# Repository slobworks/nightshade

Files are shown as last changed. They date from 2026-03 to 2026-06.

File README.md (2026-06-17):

bleh
bleh_back

This is, for all intents and purposes, a maxed-out version of the open-source, Nightshade CL-GD542x VGA card project. Basically, what this board offers the regular version is support for up to 2 megabytes of FPM DRAM installed. This board has been built by me and its basic operation verified (it works). I have _not_ tested the VESA Feature Connector, however; I am not certain that the pinout is compliant.

It's got the usual Nightshade features:

- Dedicated regulator for the internal RAMDAC, and TL431+MMBT3904 IREF circuit, for improved video quality
- Four-layer PCB and hand-tuned return paths for (hopefully) reduced noise pickup
- Supports N-well CL-GD542x chips, starting from late revision CL-GD5422 all the way up to CL-GD5429 (though you may have to change strapping resistors as needed)
- Custom footprints with longer pads for the more difficult components, to ease hand assembly using a soldering iron
- Emphasis on implementation simplicity (added regulator aside) for reduced part count and effort needed to assemble the board
- Silkscreen decorations drawn by me

The Pro variant was originally intended as a mild satire of what the 'ideal' Cirrus ISA VGA card should be, but then it spiralled out of control and became an actually viable product of its own. And it's scalable: if you don't want specific functionality (such as the second megabyte, serial EEPROM, VESA Feature Connector or the high byte BIOS socket plus its accompanying 74HCT244), then simply don't fit them.

BIOS files (apart from SEEPROM image) *not* provided here, due to uncertainty regarding the copyright. It does require a _non-interleaved_ VGA BIOS in order for it to work; most of the Cirrus BIOS files you find online are 'interleaved'. Depending on the functionality you want:
- If you want to use a BitBLT chip (GD5426 or better) and want to experiment with 2MB, you can nonetheless find a suitable (albeit padded to 64K) file, isamalaysia.bin (1.41), on the CL-GD5428 page of the VGA Legacy MkIII museum. This file has been tested and works; if your EPROM programmer complains about file size when writing 27C256, then split the file into two 32768-byte files, and use the first half to program your BIOS chips. (If you're using a 27C512, _don't_ burn this file directly to it even though it's padded; you must first split the file, and then double up the first, non-empty half. See the following paragraph.)
- If you want Serial EEPROM functionality but aren't planning on using 2MB, then you'll need a BIOS from an ISA GD542x card in order for the Serial EEPROM function to work properly. (One such BIOS that was tested to work was from a Gainward GD5424 ISA VGA card.) You will also need to pre-initialize the serial EEPROM with a valid image *before* soldering the 93C46A to the card.
- On the other hand, if all you want is just a working GD542x card, and don't care about either Serial EEPROM or 2MB, then just use whatever non-scrambled GD542x BIOS is convenient. (The beforementioned isamalaysia.bin is a reasonable candidate.)

For 27C512s, you must double up the _non-blank_ contents of the BIOS (in DOS or Windows command line, a command like 'copy /b vgabios.bin+vgabios.bin outbios.bin' is sufficient).

16-bit BIOS mode requires two PROM/EPROM/EEPROM/flash chips with identical BIOS contents.

Made in KiCAD 9.x.
Also includes gerber files so you can try it out for yourself.

Bill of materials (all parts are Surface Mount Device / SMD unless indicated otherwise):
- 1x Cirrus Logic CL-GD542x graphic chip, PQFP-160
- 2x (1MB) or 4x (2MB) 424260-compatible FPM 256Kx16 DRAM chips rated at least 70ns, SOJ-40 (this might require you to cannibalize parts from other broken cards, or roll the dice on eBay)
- 1x DIP-28 through-hole socket (2 needed for 16-bit BIOS mode)
- 1x 27C256 or compatible PROM/EPROM/flash ROM chip for BIOS, DIP-28 (2 needed for 16-bit BIOS mode)
- 1x 14.31818MHz 5032 SMD crystal (https://www.digikey.com/en/products/detail/qst/QT532G-14-31818MBBK-T/26975047)
- 1x 74HCT244, SSOP-20 or TSSOP-20 (2 needed for 16-bit BIOS mode)
- 1x LF50 or 78M05 5V LDO regulator, DPAK (https://www.digikey.com/en/products/detail/stmicroelectronics/LF50CDT-TR/591636)
- 1x TL431DBZ, SOT-23-3 (https://www.digikey.com/en/products/detail/texas-instruments/TL431BQDBZR/714694)
- 1x MMBT3904 NPN small signal transistor, SOT-23-3  (https://www.digikey.com/en/products/detail/taiwan-semiconductor-corporation/MMBT3904H-RFG/26741367)
- (Optional) 1x NM93C46 or equivalent SOIC-8 serial EEPROM (you need the one with x16 mode support) - you WILL need to initialize the serial EEPROM with a valid image *before* assembling it onto the card. Please check the directory /seeprom to get a generic image with all sub-1280x1024 SVGA refresh rates set to 60 Hz. You will also need a BIOS image from an *ISA* GD542x card for the SEEPROM functionality to work; most generic 542x BIOSes were compiled for the VLB variants, which this functionality is disabled.
- 3x 2-pin, 2.54mm pitch male jumper connectors
- (Optional) 1x 2x13 pin, 2.52mm pitch male header for VESA Feature Connector
- 1x DSUB-15-HD right angle through hole VGA connector (something akin to this: https://www.digikey.com/en/products/detail/assmann-wsw-components/A-HDF15A-KG-TAXB/1241905)
- 25x 0.1uF 0805/2012 metric ceramic caps of X5R/X7R type (https://www.digikey.com/en/products/detail/samsung-electro-mechanics/CL21B104KACNNNC/3886757)
- 7x 10uF 16V+ 2012/3216 metric ceramic caps of X5R/X7R type (these work well: https://www.digikey.com/en/products/detail/samsung-electro-mechanics/CL31B106KAHNNNE/3887462)
- 1x 22~100uF 16V 5mm x 5.3mm (or equivalent) SMD electrolytic capacitor - the higher the uF value, the better the performance, up to a point
- 4x 2.2u 0805/2012 metric ceramic caps of X5R/X7R type (1uF will likely work too)
- 1x 0.01uF / 10nF 0805/2012 metric ceramic capacitor of X5R/X7R type
- 5x 47pF 0805/2012 metric ceramic caps of C0G type
- 2x 18pF 0805/2012 metric ceramic caps of C0G type
- 1x 10K ohm 0805/2012 metric resistor
- 6x 6.8K ohm 0805/2012 metric resistors
- 5x 1K ohm 0805/2012 metric resistor
- 1x 300 ohm 0805/2012 metric resistor
- 1x 100 ohm 0805/2012 metric resistor
- 5x 75 ohm 0805/2012 metric resistors
- 1x 47 ohm 0805/2012 metric resistor
- 6x 33 ohm 0805/2012 metric resistors
- 3x 16 ohm 0805/2012 metric resistors
- (Optional) 1x PTC resettable, 9V 200mA, 0805/2012 metric polyfuse (https://www.digikey.com/en/products/detail/littelfuse-inc/0805L020YR/1212820) - this is only needed if you want to supply +5V to pin 9 of the VGA connector
- 3x 0.22~22 ohm @ 100MHz, 1210/3216 metric ferrite beads

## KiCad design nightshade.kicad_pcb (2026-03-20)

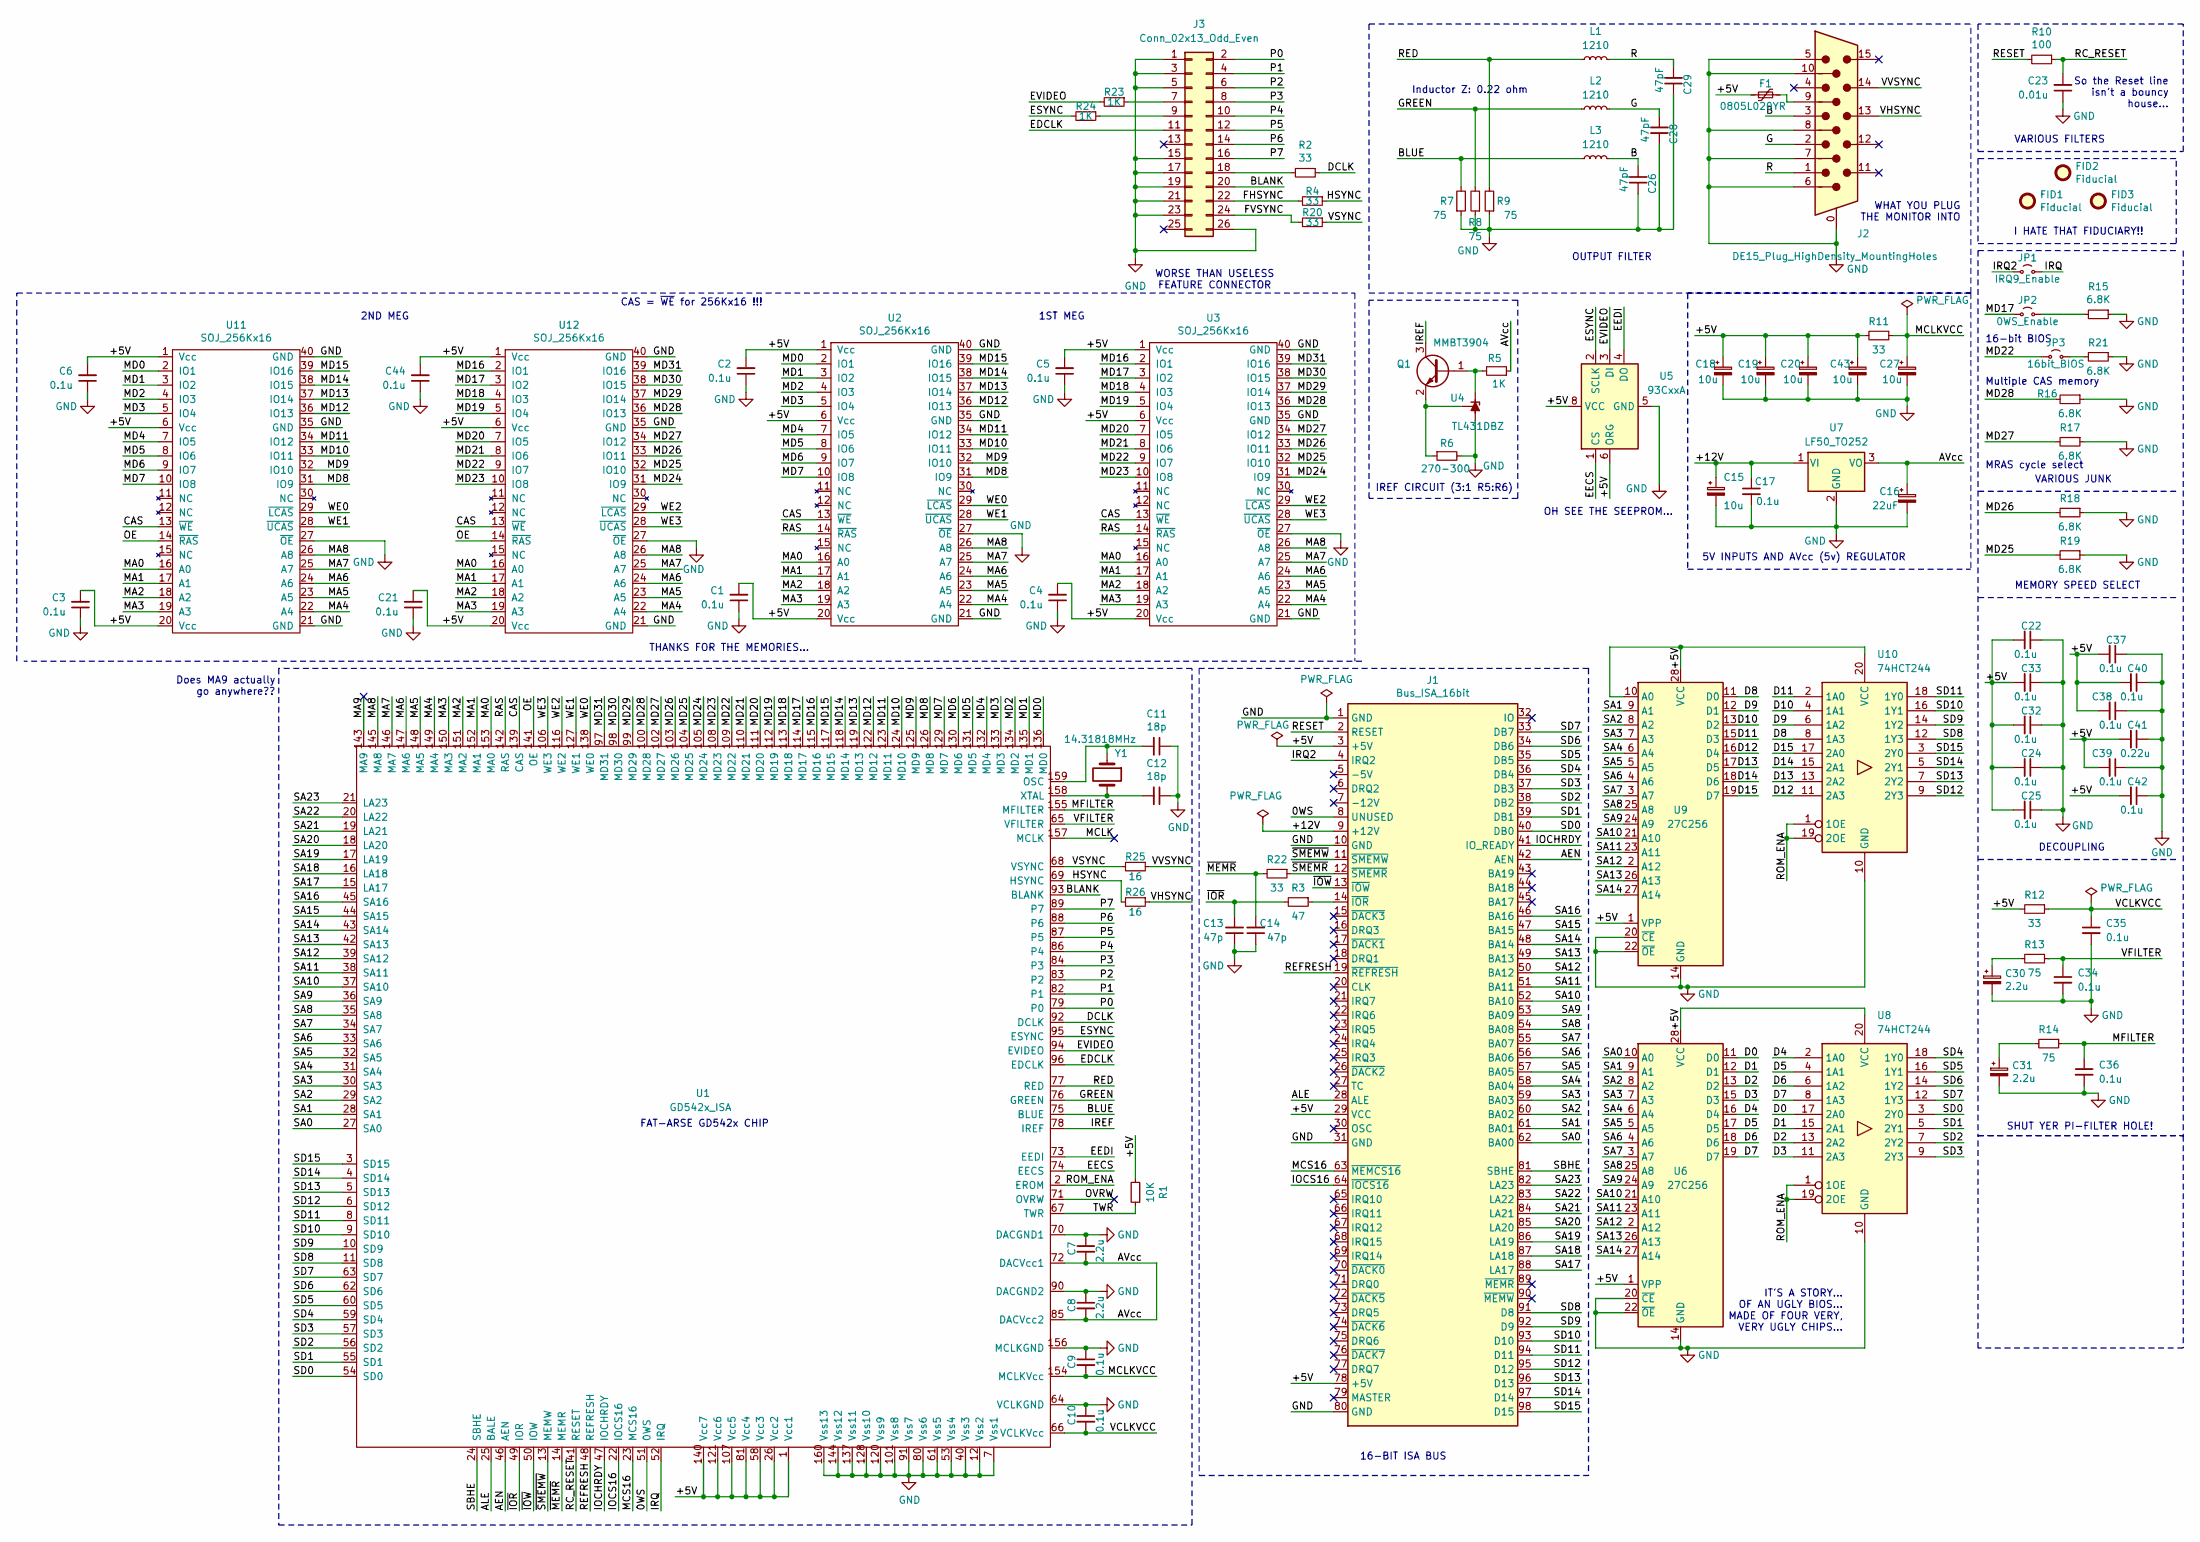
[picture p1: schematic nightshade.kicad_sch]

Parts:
C1, C2, C3, C4, C5, C6, C9, C10, C17, C21, C22, C24, C25, C32, C33, C34, C35, C36, C37, C38, C39, C40, C42, C44: 0.1u; C_0805_2012Metric
C7, C8: 2.2u; C_1206_3216Metric
C11, C12: 18p; C_0805_2012Metric
C13, C14: 47p; C_0805_2012Metric
C15, C18, C19, C20, C27, C43: 10u; C_1206_3216Metric
C16: 22uF; CP_Elec_5x5.3
C23: 0.01u; C_0805_2012Metric
C26, C28, C29: 47pF; C_0603_1608Metric
C30, C31: 2.2u; C_0805_2012Metric
C41: 0.22u; C_0805_2012Metric
F1: 0805L020YR; Fuse_0805_2012Metric
FID1, FID2, FID3: Fiducial; Fiducial_1mm_Mask2mm
J1: Bus_ISA_16bit; BUS_AT
J2: DE15_Plug_HighDensity_MountingHoles; DSUB-15-HD
J3: Conn_02x13_Odd_Even; PinHeader_2x13_P2.54mm_Vertical
JP1: IRQ9_Enable; PinHeader_1x02_P2.54mm_Vertical
JP2: 0WS_Enable; PinHeader_1x02_P2.54mm_Vertical
JP3: 16bit_BIOS; PinHeader_1x02_P2.54mm_Vertical
L1, L2, L3: 1210; L_1210_3225Metric
Q1: MMBT3904; SOT-23
R1: 10K; R_0805_2012Metric
R2, R4, R11, R12, R20: 33; R_0603_1608Metric
R3: 47; R_0805_2012Metric
R5: 1K; R_0805_2012Metric
R6: 270-300; R_0805_2012Metric
R7, R8, R9, R13, R14: 75; R_0805_2012Metric
R10: 100; R_0805_2012Metric
R15, R16, R17, R18, R19, R21: 6.8K; R_0805_2012Metric
R22: 33; R_0805_2012Metric
R23, R24: 1K; R_0603_1608Metric
R25, R26: 16; R_0805_2012Metric
U1: GD542x_ISA; PQFP-160_28x28mm_P0.65mm
U2, U3, U11, U12: SOJ_256Kx16; SOJ-40_10.16x26.44mm_P1.27mm
U4: TL431DBZ; SOT-23
U5: 93CxxA; SOIC-8_DMP-8
U6, U9: 27C256; DIP-28_W15.24mm_Socket
U7: LF50_TO252; TO-252-2
U8, U10: 74HCT244; SSOP-20_4.4_5.3x6.5mm_P0.65mm
Y1: 14.31818MHz; Crystal_SMD_5032-2Pin_5.0x3.2mm_HandSoldering

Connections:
/0WS: J1.8 (UNUSED), U1.51 (0WS)
/+5V: C1.2, C2.2, C3.2, C4.2, C5.2, C6.2, C18.1, C19.1, C20.1, C21.2, C22.2, C24.2, C25.2, C32.2, C33.2, C37.2, C38.2, C39.2, C40.2, C41.2, C42.2, C43.1, C44.2, F1.1, J1.3 (+5V), J1.29 (VCC), J1.78 (+5V), R1.2, R11.2, R12.2, U1.1 (Vcc1), U1.26 (Vcc2), U1.58 (Vcc3), U1.81 (Vcc4), U1.107 (Vcc5), U1.121 (Vcc6), U1.140 (Vcc7), U2.1 (Vcc), U2.6 (Vcc), U2.20 (Vcc), U3.1 (Vcc), U3.6 (Vcc), U3.20 (Vcc), U5.6 (ORG), U5.8 (VCC), U6.1 (VPP), U6.28 (VCC), U8.20 (VCC), U9.1 (VPP), U9.10 (A0), U9.28 (VCC), U10.20 (VCC), U11.1 (Vcc), U11.6 (Vcc), U11.20 (Vcc), U12.1 (Vcc), U12.6 (Vcc), U12.20 (Vcc)
/+12V: C15.1, C17.1, J1.9 (+12V), U7.1 (VI)
/AEN: J1.42 (AEN), U1.46 (AEN)
/ALE: J1.28 (ALE), U1.25 (BALE)
/AVcc: C7.2, C8.2, C16.1, R5.1, U1.72 (DACVcc1), U1.85 (DACVcc2), U7.3 (VO)
/B: C26.2, J2.3, L3.2
/BLANK: J3.20, U1.93 (BLANK)
/BLUE: L3.1, R7.2, U1.75 (BLUE)
/CAS: U1.139 (CAS), U2.13 (~WE), U3.13 (~WE), U11.13 (~WE), U12.13 (~WE)
/D0: U6.11 (D0), U8.17 (2A0)
/D1: U6.12 (D1), U8.15 (2A1)
/D2: U6.13 (D2), U8.13 (2A2)
/D3: U6.15 (D3), U8.11 (2A3)
/D4: U6.16 (D4), U8.2 (1A0)
/D5: U6.17 (D5), U8.4 (1A1)
/D6: U6.18 (D6), U8.6 (1A2)
/D7: U6.19 (D7), U8.8 (1A3)
/D8: U9.11 (D0), U10.8 (1A3)
/D9: U9.12 (D1), U10.6 (1A2)
/D10: U9.13 (D2), U10.4 (1A1)
/D11: U9.15 (D3), U10.2 (1A0)
/D12: U9.16 (D4), U10.11 (2A3)
/D13: U9.17 (D5), U10.13 (2A2)
/D14: U9.18 (D6), U10.15 (2A1)
/D15: U9.19 (D7), U10.17 (2A0)
/DCLK: R2.1, U1.92 (DCLK)
/EDCLK: J3.11, U1.96 (EDCLK)
/EECS: U1.74 (EECS), U5.1 (CS)
/EEDI: U1.73 (EEDI), U5.4 (DO)
/ESYNC: R24.2, U1.95 (ESYNC), U5.2 (SCLK)
/EVIDEO: R23.2, U1.94 (EVIDEO), U5.3 (DI)
/FHSYNC: J3.22, R4.2
/FVSYNC: J3.24, R20.2
/G: C28.2, J2.2, L2.2
/GREEN: L2.1, R8.2, U1.76 (GREEN)
/HSYNC: R4.1, R26.2, U1.69 (HSYNC)
/IOCHRDY: J1.41 (IO_READY), U1.47 (IOCHRDY)
/IOCS16: J1.64 (~IOCS16), U1.22 (IOCS16)
/IREF: Q1.3 (C), U1.78 (IREF)
/IRQ: JP1.2 (B), U1.52 (IRQ)
/IRQ2: J1.4 (IRQ2), JP1.1 (A)
/MA0: U1.153 (MA0), U2.16 (A0), U3.16 (A0), U11.16 (A0), U12.16 (A0)
/MA1: U1.152 (MA1), U2.17 (A1), U3.17 (A1), U11.17 (A1), U12.17 (A1)
/MA2: U1.151 (MA2), U2.18 (A2), U3.18 (A2), U11.18 (A2), U12.18 (A2)
/MA3: U1.150 (MA3), U2.19 (A3), U3.19 (A3), U11.19 (A3), U12.19 (A3)
/MA4: U1.149 (MA4), U2.22 (A4), U3.22 (A4), U11.22 (A4), U12.22 (A4)
/MA5: U1.148 (MA5), U2.23 (A5), U3.23 (A5), U11.23 (A5), U12.23 (A5)
/MA6: U1.147 (MA6), U2.24 (A6), U3.24 (A6), U11.24 (A6), U12.24 (A6)
/MA7: U1.146 (MA7), U2.25 (A7), U3.25 (A7), U11.25 (A7), U12.25 (A7)
/MA8: U1.145 (MA8), U2.26 (A8), U3.26 (A8), U11.26 (A8), U12.26 (A8)
/MA9: U1.143 (MA9)
/MCLK: U1.157 (MCLK)
/MCLKVCC: C9.2, C27.1, R11.1, U1.154 (MCLKVcc)
/MCS16: J1.63 (~MEMCS16), U1.23 (MCS16)
/MD0: U1.136 (MD0), U2.2 (IO1), U11.2 (IO1)
/MD1: U1.135 (MD1), U2.3 (IO2), U11.3 (IO2)
/MD2: U1.134 (MD2), U2.4 (IO3), U11.4 (IO3)
/MD3: U1.133 (MD3), U2.5 (IO4), U11.5 (IO4)
/MD4: U1.132 (MD4), U2.7 (IO5), U11.7 (IO5)
/MD5: U1.131 (MD5), U2.8 (IO6), U11.8 (IO6)
/MD6: U1.130 (MD6), U2.9 (IO7), U11.9 (IO7)
/MD7: U1.129 (MD7), U2.10 (IO8), U11.10 (IO8)
/MD8: U1.126 (MD8), U2.31 (IO9), U11.31 (IO9)
/MD9: U1.125 (MD9), U2.32 (IO10), U11.32 (IO10)
/MD10: U1.124 (MD10), U2.33 (IO11), U11.33 (IO11)
/MD11: U1.123 (MD11), U2.34 (IO12), U11.34 (IO12)
/MD12: U1.122 (MD12), U2.36 (IO13), U11.36 (IO13)
/MD13: U1.119 (MD13), U2.37 (IO14), U11.37 (IO14)
/MD14: U1.118 (MD14), U2.38 (IO15), U11.38 (IO15)
/MD15: U1.117 (MD15), U2.39 (IO16), U11.39 (IO16)
/MD16: U1.115 (MD16), U3.2 (IO1), U12.2 (IO1)
/MD17: JP2.1 (A), U1.114 (MD17), U3.3 (IO2), U12.3 (IO2)
/MD18: U1.113 (MD18), U3.4 (IO3), U12.4 (IO3)
/MD19: U1.112 (MD19), U3.5 (IO4), U12.5 (IO4)
/MD20: U1.111 (MD20), U3.7 (IO5), U12.7 (IO5)
/MD21: U1.110 (MD21), U3.8 (IO6), U12.8 (IO6)
/MD22: JP3.1 (A), U1.109 (MD22), U3.9 (IO7), U12.9 (IO7)
/MD23: U1.108 (MD23), U3.10 (IO8), U12.10 (IO8)
/MD24: U1.105 (MD24), U3.31 (IO9), U12.31 (IO9)
/MD25: R19.2, U1.104 (MD25), U3.32 (IO10), U12.32 (IO10)
/MD26: R18.2, U1.103 (MD26), U3.33 (IO11), U12.33 (IO11)
/MD27: R17.2, U1.102 (MD27), U3.34 (IO12), U12.34 (IO12)
/MD28: R16.2, U1.100 (MD28), U3.36 (IO13), U12.36 (IO13)
/MD29: U1.99 (MD29), U3.37 (IO14), U12.37 (IO14)
/MD30: U1.98 (MD30), U3.38 (IO15), U12.38 (IO15)
/MD31: U1.97 (MD31), U3.39 (IO16), U12.39 (IO16)
/MFILTER: C36.1, R14.1, U1.155 (MFILTER)
/OE: U1.141 (OE), U11.14 (~RAS), U12.14 (~RAS)
/OVRW: U1.71 (OVRW)
/P0: J3.2, U1.79 (P0)
/P1: J3.4, U1.82 (P1)
/P2: J3.6, U1.83 (P2)
/P3: J3.8, U1.84 (P3)
/P4: J3.10, U1.86 (P4)
/P5: J3.12, U1.87 (P5)
/P6: J3.14, U1.88 (P6)
/P7: J3.16, U1.89 (P7)
/R: C29.2, J2.1, L1.2
/RAS: U1.142 (RAS), U2.14 (~RAS), U3.14 (~RAS)
/RC_RESET: C23.2, R10.1, U1.41 (RESET)
/RED: L1.1, R9.2, U1.77 (RED)
/REFRESH: J1.19 (~REFRESH), U1.48 (REFRESH)
/RESET: J1.2 (RESET), R10.2
/ROM_ENA: U1.2 (EROM), U8.1 (1OE), U8.19 (2OE), U10.1 (1OE), U10.19 (2OE)
/SA0: J1.62 (BA00), U1.27 (SA0), U6.10 (A0)
/SA1: J1.61 (BA01), U1.28 (SA1), U6.9 (A1), U9.9 (A1)
/SA2: J1.60 (BA02), U1.29 (SA2), U6.8 (A2), U9.8 (A2)
/SA3: J1.59 (BA03), U1.30 (SA3), U6.7 (A3), U9.7 (A3)
/SA4: J1.58 (BA04), U1.31 (SA4), U6.6 (A4), U9.6 (A4)
/SA5: J1.57 (BA05), U1.32 (SA5), U6.5 (A5), U9.5 (A5)
/SA6: J1.56 (BA06), U1.33 (SA6), U6.4 (A6), U9.4 (A6)
/SA7: J1.55 (BA07), U1.34 (SA7), U6.3 (A7), U9.3 (A7)
/SA8: J1.54 (BA08), U1.35 (SA8), U6.25 (A8), U9.25 (A8)
/SA9: J1.53 (BA09), U1.36 (SA9), U6.24 (A9), U9.24 (A9)
/SA10: J1.52 (BA10), U1.37 (SA10), U6.21 (A10), U9.21 (A10)
/SA11: J1.51 (BA11), U1.38 (SA11), U6.23 (A11), U9.23 (A11)
/SA12: J1.50 (BA12), U1.39 (SA12), U6.2 (A12), U9.2 (A12)
/SA13: J1.49 (BA13), U1.42 (SA13), U6.26 (A13), U9.26 (A13)
/SA14: J1.48 (BA14), U1.43 (SA14), U6.27 (A14), U9.27 (A14)
/SA15: J1.47 (BA15), U1.44 (SA15)
/SA16: J1.46 (BA16), U1.45 (SA16)
/SA17: J1.88 (LA17), U1.15 (LA17)
/SA18: J1.87 (LA18), U1.16 (LA18)
/SA19: J1.86 (LA19), U1.17 (LA19)
/SA20: J1.85 (LA20), U1.18 (LA20)
/SA21: J1.84 (LA21), U1.19 (LA21)
/SA22: J1.83 (LA22), U1.20 (LA22)
/SA23: J1.82 (LA23), U1.21 (LA23)
/SBHE: J1.81 (SBHE), U1.24 (SBHE)
/SD0: J1.40 (DB0), U1.54 (SD0), U8.3 (2Y0)
/SD1: J1.39 (DB1), U1.55 (SD1), U8.5 (2Y1)
/SD2: J1.38 (DB2), U1.56 (SD2), U8.7 (2Y2)
/SD3: J1.37 (DB3), U1.57 (SD3), U8.9 (2Y3)
/SD4: J1.36 (DB4), U1.59 (SD4), U8.18 (1Y0)
/SD5: J1.35 (DB5), U1.60 (SD5), U8.16 (1Y1)
/SD6: J1.34 (DB6), U1.62 (SD6), U8.14 (1Y2)
/SD7: J1.33 (DB7), U1.63 (SD7), U8.12 (1Y3)
/SD8: J1.91 (D8), U1.11 (SD8), U10.12 (1Y3)
/SD9: J1.92 (D9), U1.10 (SD9), U10.14 (1Y2)
/SD10: J1.93 (D10), U1.9 (SD10), U10.16 (1Y1)
/SD11: J1.94 (D11), U1.8 (SD11), U10.18 (1Y0)
/SD12: J1.95 (D12), U1.6 (SD12), U10.9 (2Y3)
/SD13: J1.96 (D13), U1.5 (SD13), U10.7 (2Y2)
/SD14: J1.97 (D14), U1.4 (SD14), U10.5 (2Y1)
/SD15: J1.98 (D15), U1.3 (SD15), U10.3 (2Y0)
/TWR: R1.1, U1.67 (TWR)
/VCLKVCC: C10.2, C35.1, R12.1, U1.66 (VCLKVcc)
/VFILTER: C34.1, R13.1, U1.65 (VFILTER)
/VHSYNC: J2.13, R26.1
/VSYNC: R20.1, R25.2, U1.68 (VSYNC)
/VVSYNC: J2.14, R25.1
/WE0: U1.138 (WE0), U2.29 (~LCAS), U11.29 (~LCAS)
/WE1: U1.127 (WE1), U2.28 (~UCAS), U11.28 (~UCAS)
/WE2: U1.116 (WE2), U3.29 (~LCAS), U12.29 (~LCAS)
/WE3: U1.106 (WE3), U3.28 (~UCAS), U12.28 (~UCAS)
/~IOR: C13.2, R3.2, U1.49 (IOR)
/~IOW: J1.13 (~IOW), U1.50 (IOW)
/~MEMR: C14.2, R22.2, U1.14 (MEMR)
/~SMEMR: J1.12 (~SMEMR), R22.1
/~SMEMW: J1.11 (~SMEMW), U1.13 (MEMW)
GND: C1.1, C2.1, C3.1, C4.1, C5.1, C6.1, C7.1, C8.1, C9.1, C10.1, C11.1, C12.1, C13.1, C14.1, C15.2, C16.2, C17.2, C18.2, C19.2, C20.2, C21.1, C22.1, C23.1, C24.1, C25.1, C26.1, C27.2, C28.1, C29.1, C30.2, C31.2, C32.1, C33.1, C34.2, C35.2, C36.2, C37.1, C38.1, C39.1, C40.1, C41.1, C42.1, C43.2, C44.1, J1.1 (GND), J1.10 (GND), J1.31 (GND), J1.80 (GND), J2.0, J2.5, J2.6, J2.7, J2.8, J2.10, J3.1, J3.3, J3.5, J3.15, J3.17, J3.19, J3.21, J3.23, J3.26, R6.2, R7.1, R8.1, R9.1, R15.1, R16.1, R17.1, R18.1, R19.1, R21.1, U1.7 (Vss1), U1.12 (Vss2), U1.40 (Vss3), U1.53 (Vss4), U1.61 (Vss5), U1.64 (VCLKGND), U1.70 (DACGND1), U1.80 (Vss6), U1.90 (DACGND2), U1.91 (Vss7), U1.101 (Vss8), U1.120 (Vss9), U1.128 (Vss10), U1.137 (Vss11), U1.144 (Vss12), U1.156 (MCLKGND), U1.160 (Vss13), U2.21 (GND), U2.27 (~OE), U2.35 (GND), U2.40 (GND), U3.21 (GND), U3.27 (~OE), U3.35 (GND), U3.40 (GND), U4.3 (A), U5.5 (GND), U6.14 (GND), U6.20 (~CE), U6.22 (~OE), U7.2 (GND), U8.10 (GND), U9.14 (GND), U9.20 (~CE), U9.22 (~OE), U10.10 (GND), U11.21 (GND), U11.27 (~OE), U11.35 (GND), U11.40 (GND), U12.21 (GND), U12.27 (~OE), U12.35 (GND), U12.40 (GND)
unnamed: C30.1, R13.2
unnamed: C31.1, R14.2
unnamed: F1.2, J2.9
unnamed: J1.14 (~IOR), R3.1
unnamed: J3.7, R23.1
unnamed: J3.9, R24.1
unnamed: J3.18, R2.2
unnamed: JP2.2 (B), R15.2
unnamed: JP3.2 (B), R21.2
unnamed: Q1.1 (B), R5.2, U4.1 (K)
unnamed: Q1.2 (E), R6.1, U4.2 (REF)
unnamed: C11.2, U1.159 (OSC), Y1.1
unnamed: C12.2, U1.158 (XTAL), Y1.2

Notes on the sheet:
FAT-ARSE GD542x CHIP
16-BIT ISA BUS
WHAT YOU PLUG THE MONITOR INTO
DECOUPLING
So the Reset line isn't a bouncy house...
MRAS cycle select
THANKS FOR THE MEMORIES...
1ST MEG
Does MA9 actually go anywhere??
IREF CIRCUIT (3:1 R5:R6)
Inductor Z: 0.22 ohm
SHUT YER PI-FILTER HOLE!
16-bit BIOS
OH SEE THE SEEPROM...
VARIOUS FILTERS
2ND MEG
MEMORY SPEED SELECT
I HATE THAT FIDUCIARY!!
Multiple CAS memory
VARIOUS JUNK
IT'S A STORY... OF AN UGLY BIOS... MADE OF FOUR VERY, VERY UGLY CHIPS...
OUTPUT FILTER
5V INPUTS AND AVcc (5v) REGULATOR
CAS = ~{WE} for 256Kx16 !!!
WORSE THAN USELESS FEATURE CONNECTOR

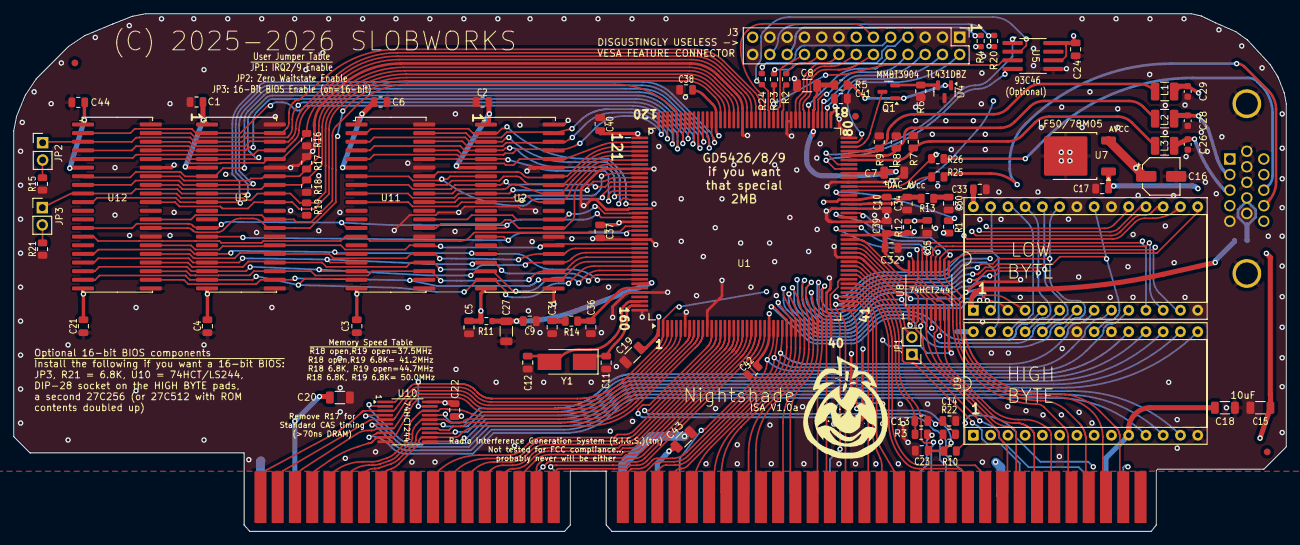
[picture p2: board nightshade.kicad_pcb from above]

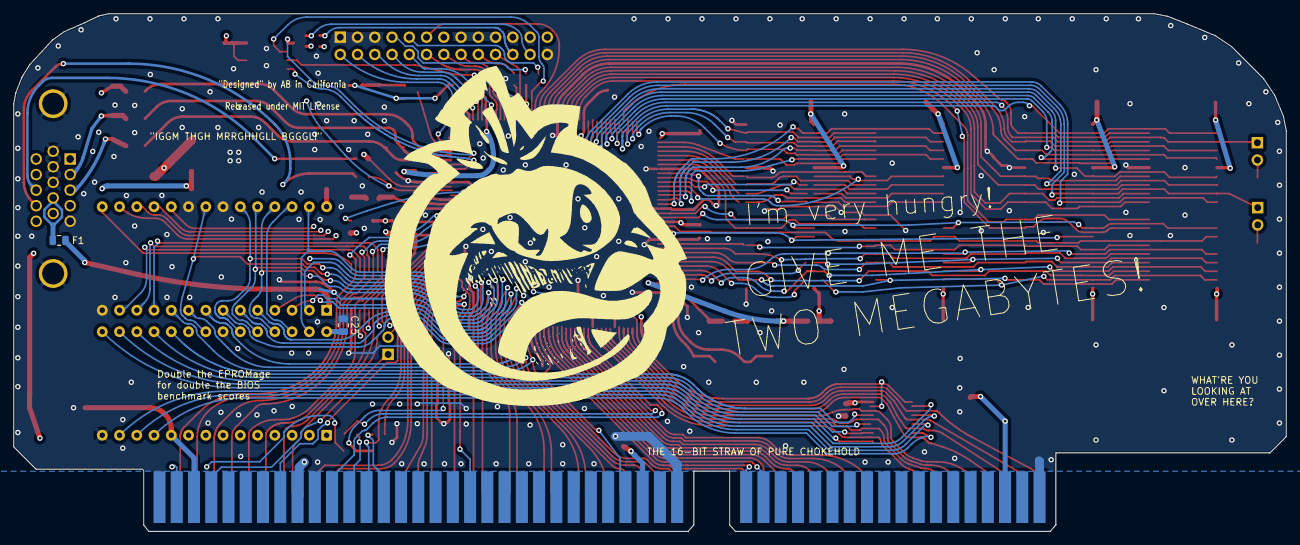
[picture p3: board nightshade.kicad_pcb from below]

Board: 4 copper layers, 187.3 x 76.2 mm, 97 parts (2 on the bottom side), 172 nets.

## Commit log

2026-01-19 Add files via upload
    Say hello to Killer Tomato!
    [nightshade-+5V_Cu.gbr, nightshade-B_Cu.gbr, nightshade-B_Mask.gbr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]
2026-01-19 Add files via upload
    Added .bom file
2026-01-19 Update README.md
    Disambiguated 'DIP-28 socket' -> 'DIP-28 through-hole socket'.
2026-01-21 Add files via upload
    A big bunch of little bug fixes, and combined a capacitor and DIP-28 socket to fix an issue where a ceramic cap was placed too close to the edge connector (mechanical stress issue).
    [nightshade-+5V_Cu.gbr, nightshade-B_Cu.gbr, nightshade-B_Mask.gbr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]
2026-01-21 Add files via upload
    Changed combined footprint back to discrete individual cap and socket. Moved capacitor out from underneath the socket footprint. There, automated assembly should be able to install everything now.
    [nightshade-+5V_Cu.gbr, nightshade-B_Cu.gbr, nightshade-B_Mask.gbr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]
2026-01-22 Add files via upload
    More minor fixes.
    [nightshade-+5V_Cu.gbr, nightshade-B_Cu.gbr, nightshade-B_Mask.gbr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]
2026-01-23 Update README.md
    Just remembered that I didn't test the VESA Feature Connector
2026-01-26 Add files via upload
    1.0a - Moderate clean-up of routing in some areas, improving ground pour contiguity and redistributing some of the ground pour vias so they're a little smarter placed in general.
    [nightshade-+5V_Cu.gbr, nightshade-B_Cu.gbr, nightshade-B_Mask.gbr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]
2026-03-06 Update README.md
    Changed 0.22uF caps to 0.1uF - I tested 0.1uF on a board and it seems to work pretty much identically to the 0.22uF fitted boards, but with cheaper parts
2026-03-06 Add files via upload
    Cheaper parts that do not affect function! Yay!
    [nightshade.kicad_pcb, nightshade.kicad_sch]
2026-03-20 Add files via upload
    Replaced all textual references to 'Killer Tomato' to less copyright infringing alternatives. Graphics are not changed yet, they will be eventually once time permits.
    [nightshade-+5V_Cu.gbr, nightshade-B_Cu.gbr, nightshade-B_Mask.gbr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]
2026-06-17 Update README.md
    Corrected missing 1K resistors in BOM

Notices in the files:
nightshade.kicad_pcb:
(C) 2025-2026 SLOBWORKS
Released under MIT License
